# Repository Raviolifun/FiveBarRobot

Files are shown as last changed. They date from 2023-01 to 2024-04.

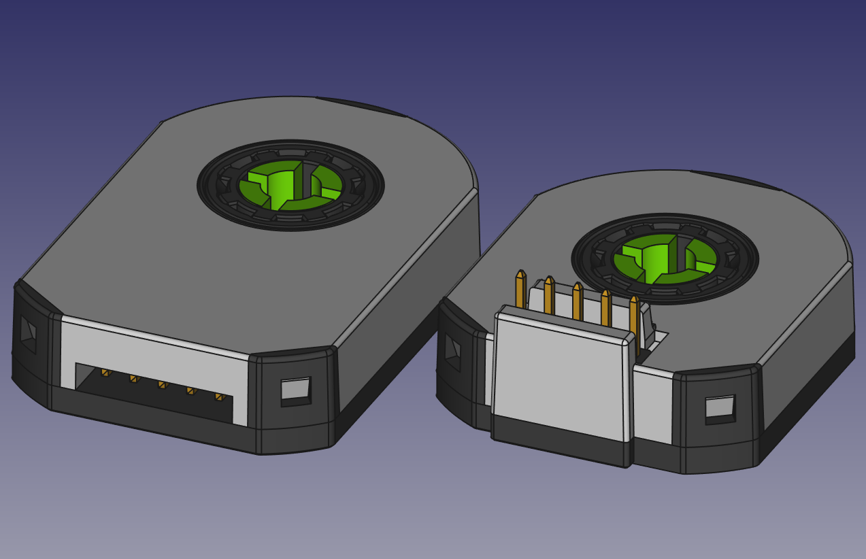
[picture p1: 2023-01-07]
CAD_Model/Motor/Electronics/cui-devices-atm102-atm103-encoders-1.snapshot.5/Encoders.png

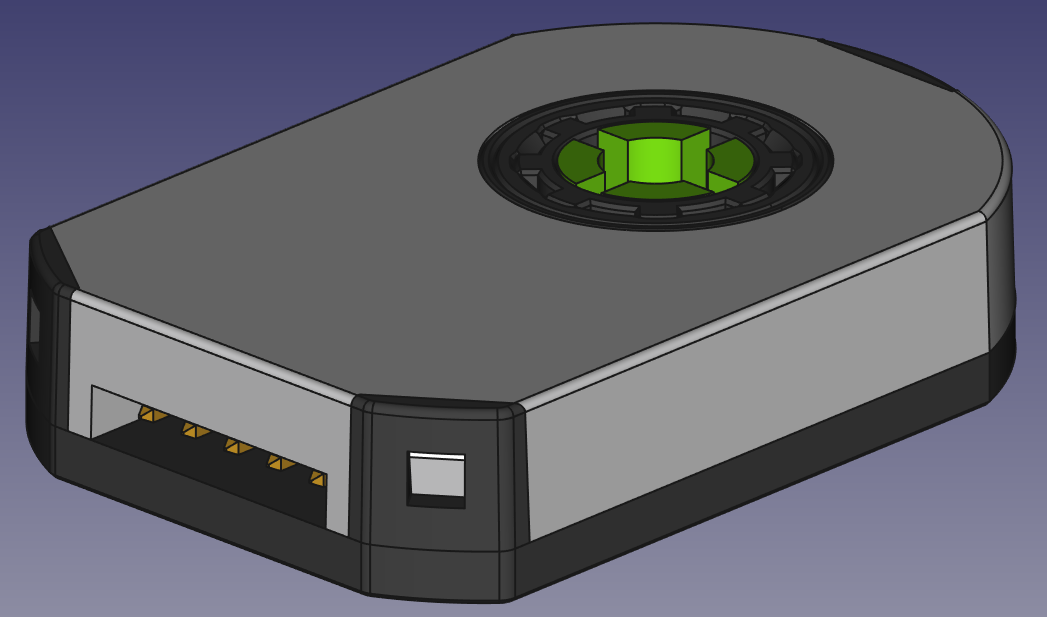
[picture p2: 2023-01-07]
CAD_Model/Motor/Electronics/cui-devices-atm102-atm103-encoders-1.snapshot.5/ATM102 Encoder.png

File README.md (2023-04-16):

Five Bar Robot
====================


Air Hockey Playing Robot
---------------------
Air hockey is used as a demonstration for the five bar robot's control.

Installation instructions
---------------------
Using this [guide](https://roboticsbackend.com/using-ros-on-raspberry-pi-best-practices/)
we downloaded Ubuntu Mate for the raspberry pi.
In tandem, we used this [guide](https://ubuntu-mate.org/raspberry-pi/install/)
to install the right version for our case (arm64 Jammy Jellyfish, 22.04.1 LTS.)
These instructions were not followed exactly, and we used a different flasher called balenaEtcher.

You will have to install a few python packages.

SAMPLE FOR WHAT THIS LOOKS LIKE IN THE README

Refer to the KivyMD page for installing the ui components https://github.com/kivymd/KivyMD
You will have to run these pip install commands for the app to work.
For all other installations, install based on the error messages on import.
```bash
pip install https://github.com/kivy/kivy/archive/master.zip
pip install https://github.com/kivymd/KivyMD/archive/master.zip
```

Hardware Requirements
---------------------
This project was built to run on Ubuntu Mate for the raspberry pi. However, many of the python files included in this
repository can run on Windows machines with no issues.

When first connecting to the ODrive, your computer may have difficultly communicating with the device.
This is often because your computer lacks the drivers required to communicate with the device.
These can be installed by using [Zadig](https://zadig.akeo.ie/), viewing all devices via the options menu, and then
installing "WinUSB" to the native interface for use with the odrivetool. Restart the computer if issues persist.
If none of these options work, refer to the [Odrive documentation](https://docs.odriverobotics.com/v/0.5.5/troubleshooting.html#troubleshooting) for trouble shooting.

The Story
---------------------

### The Inspiration
I enjoy doing fun projects, why else would you make something like this? Actually, it was a project I wanted to do for my
honor's thesis for a class I had been a TA for. I thought the rich dynamics and its design would allow for a really fun
project for the students to work on, so I decided to make it happen!

### What it does
A vision system located above the table tells the 5-bar where to position itself
with respect to the table. This is then fed through a coordinate transform before inverse kinematics are used to determine
possible joint angle that would satisfy the desired positions. At this point, a path is planned between
the current location and the desired location, at which point a following algorithm is used so the 5-bar can make its
way to the final position.

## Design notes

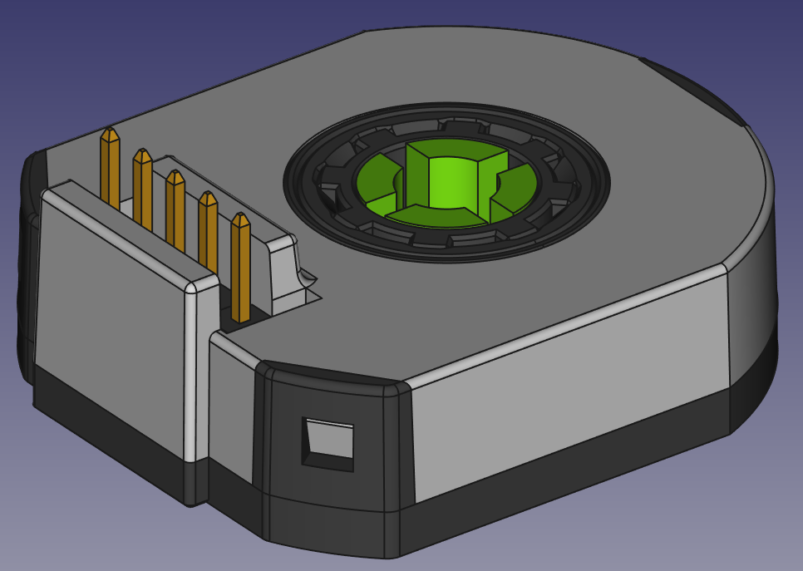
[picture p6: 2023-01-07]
CAD_Model/Motor/Electronics/cui-devices-atm102-atm103-encoders-1.snapshot.5/ATM103 Encoder.png

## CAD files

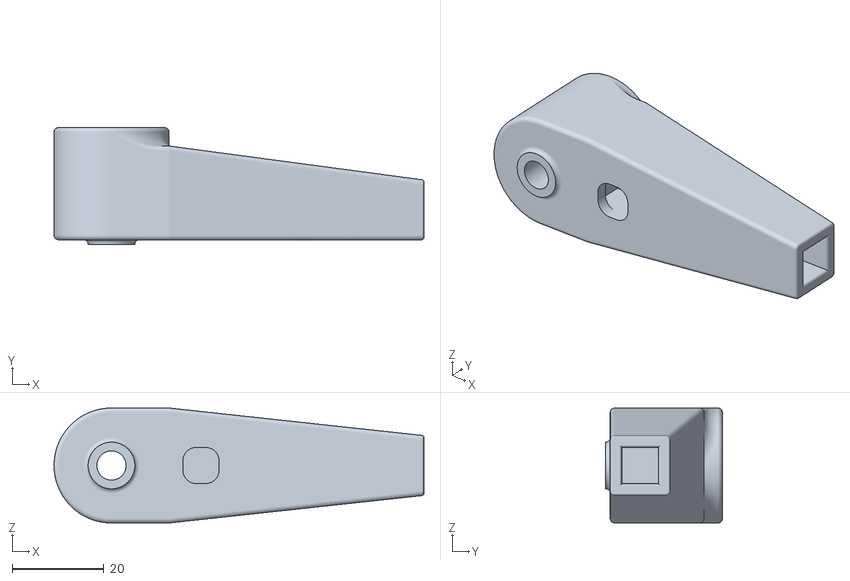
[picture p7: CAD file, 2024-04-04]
CAD_Model/Export3DPrinting/Save_LinkageMainV2.STL
80.4 x 25.4 x 25.0

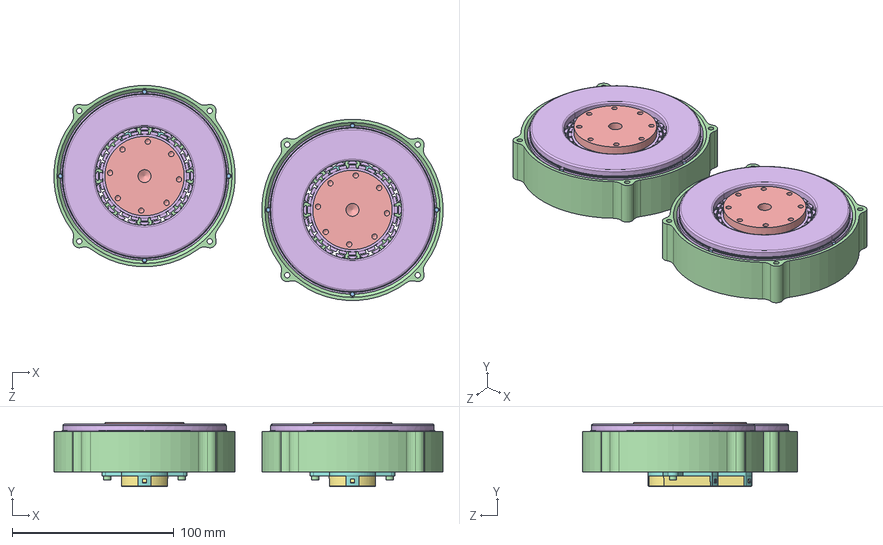
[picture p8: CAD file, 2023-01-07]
CAD_Model/Full_ASM.SLDASM
240.2 x 39.5 x 132.7 mm
0.500 ID x 0.875 OD x 0.281 WD (Radial Bearing) (217-3337) x 4
97633A200_External Retaining Ring x 2
97049A330_Undersized Dowel Pin x 8
91290A100_Black-Oxide Alloy Steel Socket Head Screw x 4
Body007^Array002_ATM102 Encoder(2)_ATM102 Encoder x 10
Body008^Array003_ATM102 Encoder(2)_ATM102 Encoder x 10
Body^ATM102 Encoder(2)_ATM102 Encoder x 2
Body001^ATM102 Encoder(2)_ATM102 Encoder x 2
Chamfer002^ATM102 Encoder(2)_ATM102 Encoder x 2
Chamfer004^ATM102 Encoder(2)_ATM102 Encoder x 2
Body006^ATM102 Encoder(2)_ATM102 Encoder x 2
Stator x 2
Rotor x 2
RI100-210120 x 2

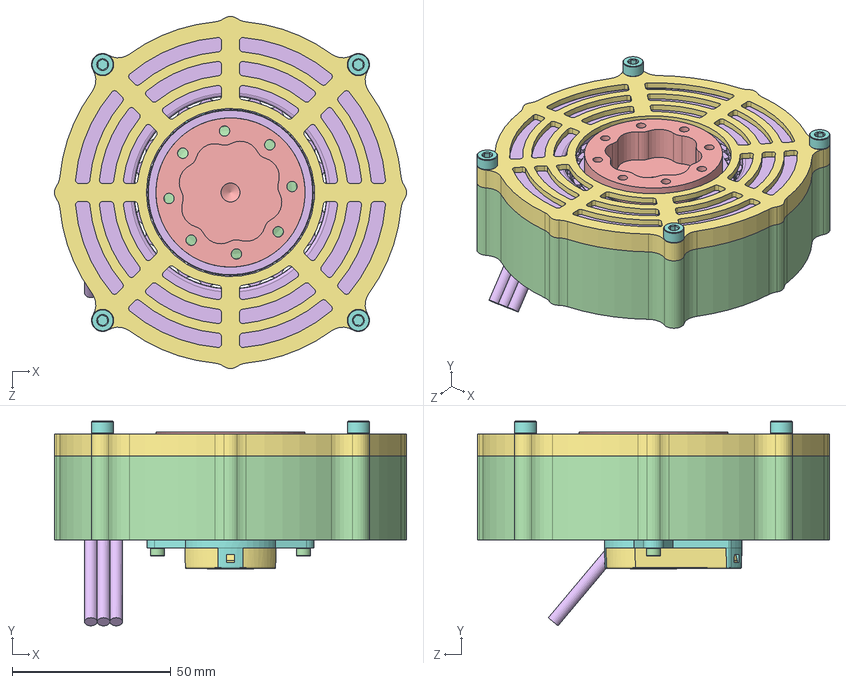
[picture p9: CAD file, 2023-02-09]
CAD_Model/Motor/MainMotorASM.SLDASM
110.9 x 64.5 x 110.9 mm
60355K45_Ball Bearing x 2
97633A170_External Retaining Ring
97049A330_Undersized Dowel Pin x 4
91290A100_Black-Oxide Alloy Steel Socket Head Screw x 2
Body007^Array002_ATM102 Encoder(2)_ATM102 Encoder x 5
Body008^Array003_ATM102 Encoder(2)_ATM102 Encoder x 5
Body^ATM102 Encoder(2)_ATM102 Encoder
Body001^ATM102 Encoder(2)_ATM102 Encoder
Chamfer002^ATM102 Encoder(2)_ATM102 Encoder
Chamfer004^ATM102 Encoder(2)_ATM102 Encoder
Body006^ATM102 Encoder(2)_ATM102 Encoder
Stator
Rotor
RI100-210120
Part2^MainMotorASM
91290A144_Alloy Steel Socket Head Screw x 4

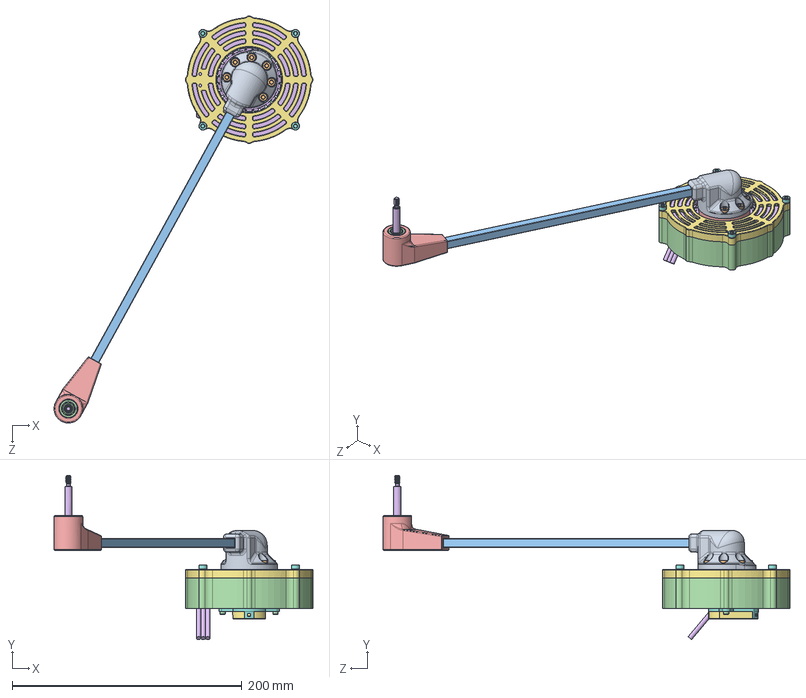
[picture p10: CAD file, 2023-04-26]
CAD_Model/Linkage/Linkage_ASM.SLDASM
225.2 x 142.9 x 354.1 mm
60355K45_Ball Bearing x 2
97633A170_External Retaining Ring
97049A330_Undersized Dowel Pin x 4
91290A100_Black-Oxide Alloy Steel Socket Head Screw x 2
Body007^Array002_ATM102 Encoder(2)_ATM102 Encoder x 5
Body008^Array003_ATM102 Encoder(2)_ATM102 Encoder x 5
Body^ATM102 Encoder(2)_ATM102 Encoder
Body001^ATM102 Encoder(2)_ATM102 Encoder
Chamfer002^ATM102 Encoder(2)_ATM102 Encoder
Chamfer004^ATM102 Encoder(2)_ATM102 Encoder
Body006^ATM102 Encoder(2)_ATM102 Encoder
Stator
Rotor
RI100-210120
Part2^MainMotorASM
91290A144_Alloy Steel Socket Head Screw x 4
Shoulder Mount
91290A140_Alloy Steel Socket Head Screw x 6
Shoulder Arm
6455K8_Plastic Ball Bearing x 2
Elbow1V2
93897A322_Nylon Shoulder Screws

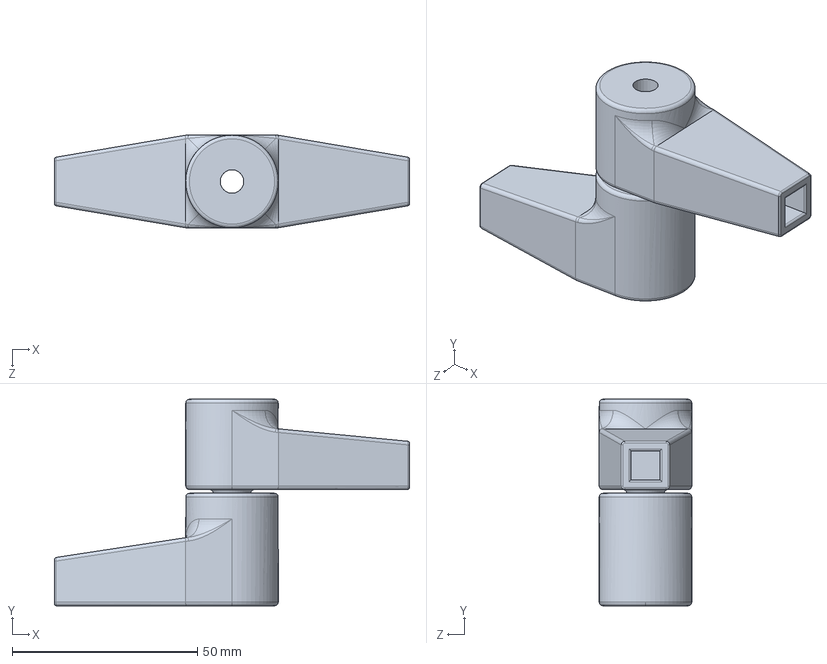
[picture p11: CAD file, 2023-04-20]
CAD_Model/Linkage/LinkageMainV2.SLDPRT
95.9 x 55.8 x 25.0 mm

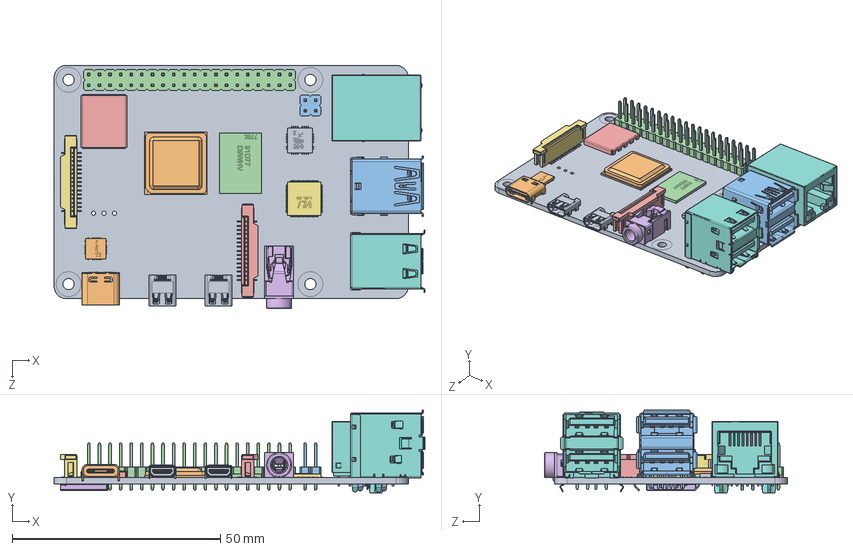
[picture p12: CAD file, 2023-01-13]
CAD_Model/Electronics/raspberry-pi-4-model-b-1.snapshot.3/Raspberry Pi 4 Model B.SLDASM
89.0 x 19.9 x 58.4 mm
PCB, RPi4ModelB
Broadcom BCM2711B0 CPU, RPi4ModelB
2.54 mm DUPONT MALE PIN HEADER, POE, 2X2, RPi4ModelB
2.54 mm DUPONT MALE PIN HEADER, IO, 2X20, RPi4ModelB
Camera Connector, RPi4ModelB
Microphone Plug, RPi4ModelB
Display Connector, RPi4ModelB
Gigabit Ethernet Port, RPi4ModelB
Female Micro HDMI Connector, RPi4ModelB x 2
Female USB Type C Connector, RPi4ModelB
2X USB3.0 PORTS, RPi4ModelB
91D77 D9WHV 778K, 4 GB LPDDR4 SDRAM, RPi4ModelB
Cypress CYW43455 Wireless Module Cover, RPi4ModelB
SD Card Slot, RPi4ModelB
VIA VL805 PCIe USB 3.0 controller, RPi4ModelB
2X USB2.0 PORTS, RPi4ModelB
Broadcom BCM54213PE Gigabit Ethernet Transceiver, RPi4ModelB
MxL7704 Universal PMIC, RPi4ModelB

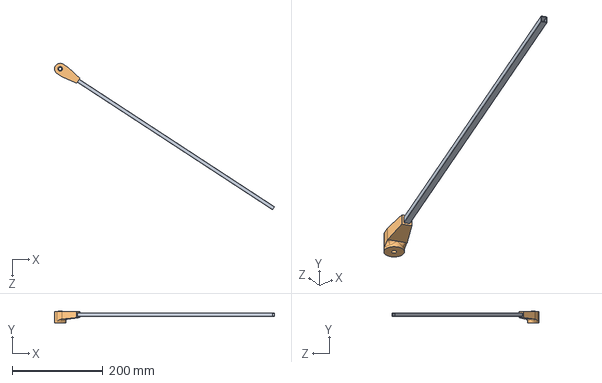
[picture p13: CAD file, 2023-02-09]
CAD_Model/Linkage/Forarm_ASM.SLDASM
485.6 x 25.4 x 323.5 mm
Forearm
Elbow2V2

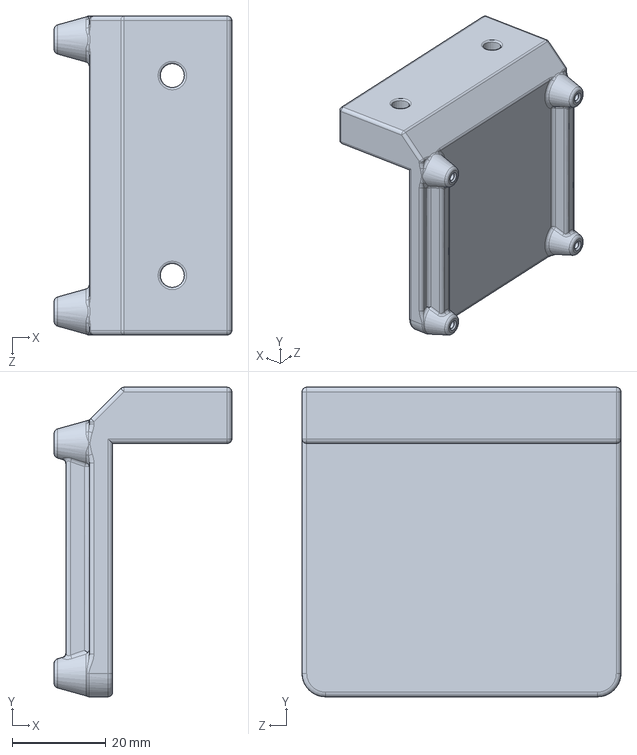
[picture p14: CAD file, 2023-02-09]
CAD_Model/AirTable/Raspi Controller Mount.SLDPRT
37.9 x 66.0 x 68.0 mm

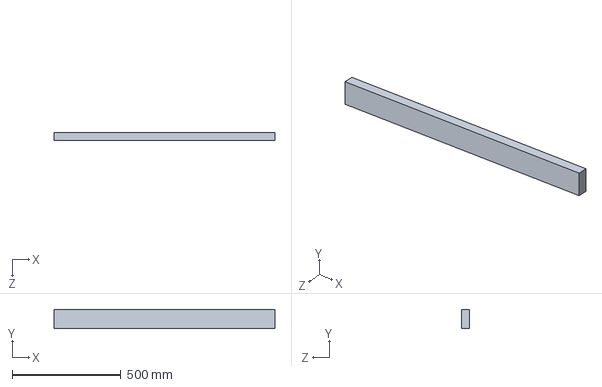
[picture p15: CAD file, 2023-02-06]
CAD_Model/AirTable/SubParts/BottomSupport3.SLDPRT
1016.0 x 88.9 x 38.1 mm

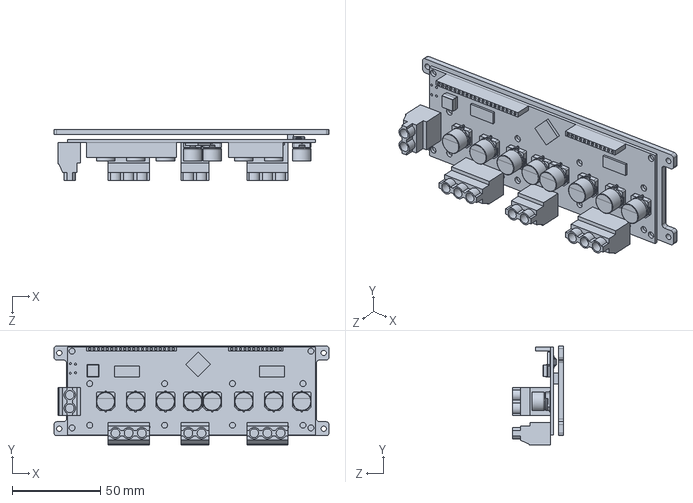
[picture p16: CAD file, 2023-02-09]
CAD_Model/Electronics/motor-driver-odrive-v3-6-1.snapshot.2/motor driver ODRIVE V3.6.SLDPRT
156.0 x 56.1 x 29.1 mm

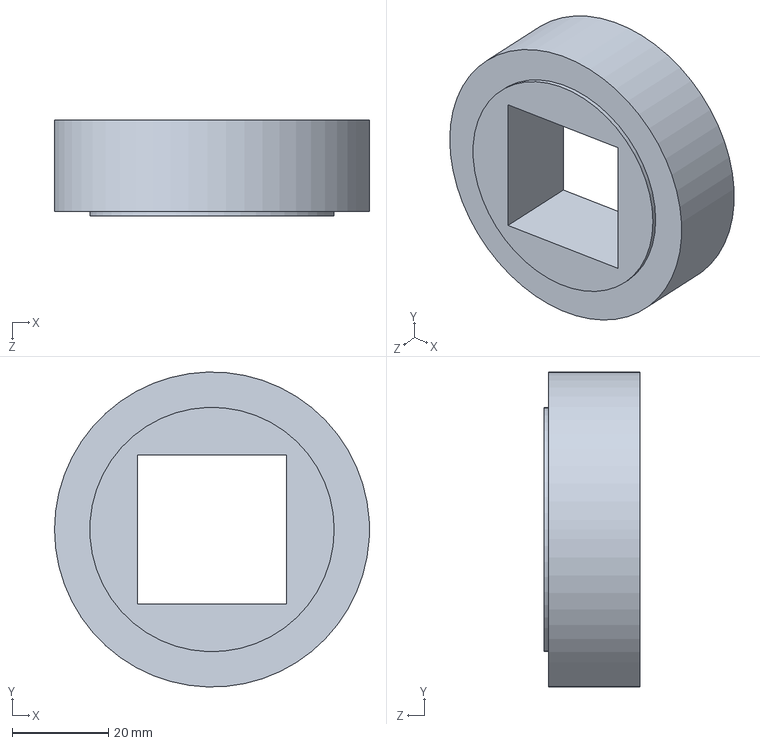
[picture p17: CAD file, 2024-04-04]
CAD_Model/Electronics/NeopixelRinglightMount.SLDPRT
65.5 x 65.5 x 20.0 mm

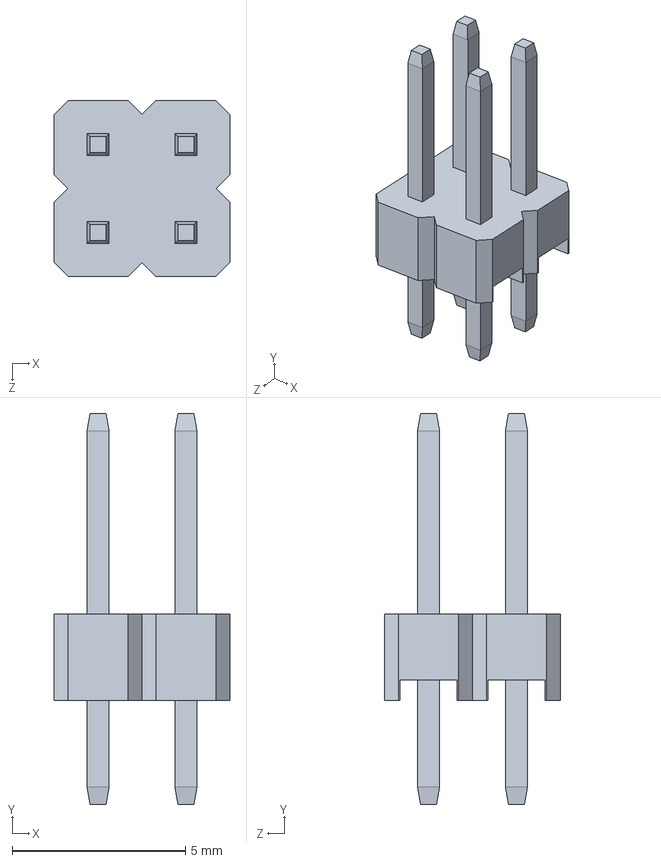
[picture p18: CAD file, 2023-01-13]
CAD_Model/Electronics/raspberry-pi-4-model-b-1.snapshot.3/2.54 mm DUPONT MALE PIN HEADER, POE, 2X2, RPi4ModelB.SLDPRT
5.08 x 11.3 x 5.08 mm

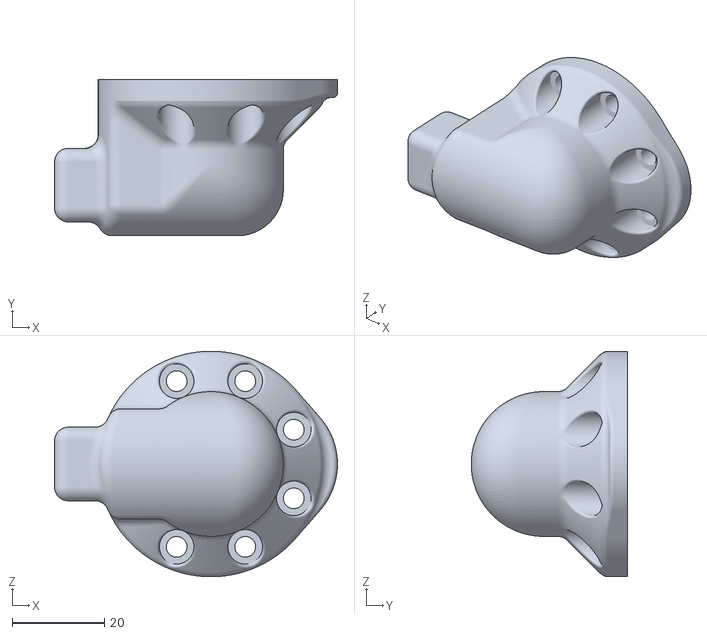
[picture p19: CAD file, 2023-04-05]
CAD_Model/Export3DPrinting/ToPrint/Robot_ShoulderMount.STL
61.5 x 34.0 x 49.0

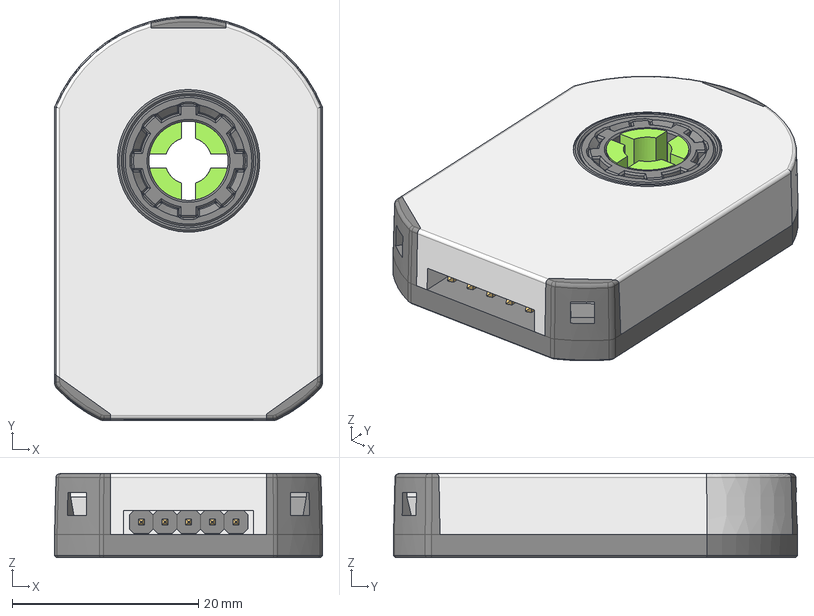
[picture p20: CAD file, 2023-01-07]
CAD_Model/Motor/Electronics/cui-devices-atm102-atm103-encoders-1.snapshot.5/ATM102 Encoder.step
28.8 x 43.4 x 9.03 mm

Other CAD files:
CAD_Model/Linkage/Save_LinkageMainV2.SLDPRT
CAD_Model/Motor/Electronics/cui-devices-atm102-atm103-encoders-1.snapshot.5/FreeCAD Files/Encoders.FCStd
CAD_Model/Motor/StatorRotor/RI100-210120.stp
CAD_Model/TestSystem/TestSystem_1.STL
CAD_Model/AirTable/Air Table.SLDPRT
CAD_Model/AirTable/Air TableTOP.SLDDRW
CAD_Model/AirTable/Ducts.STEP
CAD_Model/AirTable/Edge_Guard.SLDPRT
CAD_Model/AirTable/Electronics Mount.SLDPRT
CAD_Model/AirTable/Motor Controller Mount.SLDPRT
CAD_Model/AirTable/MotorMount.SLDPRT
CAD_Model/AirTable/Mounting for Motors.SLDPRT
CAD_Model/AirTable/Puck.3mf
CAD_Model/AirTable/Puck.SLDPRT
CAD_Model/AirTable/Puck.STL
CAD_Model/AirTable/SubParts/BottomSupport.SLDDRW
CAD_Model/AirTable/SubParts/BottomSupport.SLDPRT
CAD_Model/AirTable/SubParts/BottomSupport2.SLDPRT
CAD_Model/AirTable/SubParts/BottomSupport4.SLDPRT
CAD_Model/AirTable/SubParts/Corner Locator1.SLDPRT
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

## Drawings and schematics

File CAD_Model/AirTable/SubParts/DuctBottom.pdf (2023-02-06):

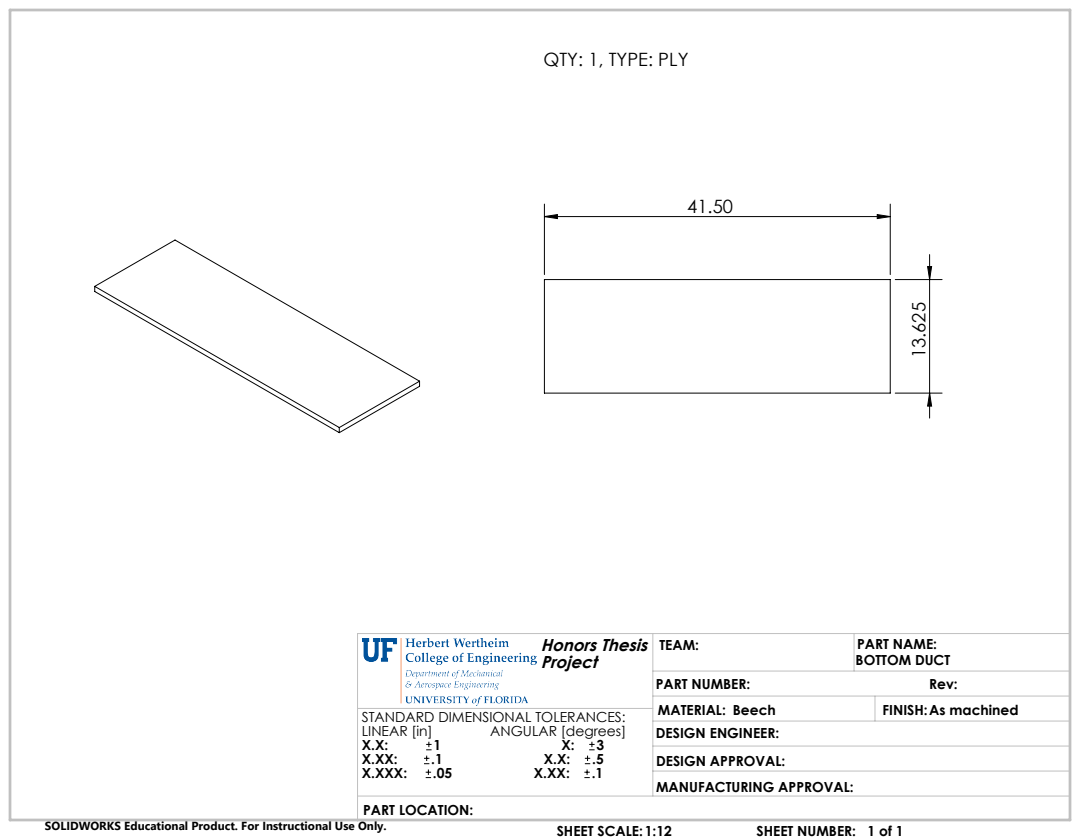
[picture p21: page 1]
Honors Thesis; DESIGN ENGINEER: DESIGN APPROVAL:; PART NUMBER:; SHEET SCALE:; SHEET NUMBER:; Beech; As machined; PART NAME: BOTTOM DUCT; LINEAR [in]; ANGULAR [degrees]; X.XXX:; MANUFACTURING APPROVAL:

QTY: 1, TYPE: PLY

STANDARD DIMENSIONAL TOLERANCES:
PART LOCATION:

SOLIDWORKS Educational Product. For Instructional Use Only.

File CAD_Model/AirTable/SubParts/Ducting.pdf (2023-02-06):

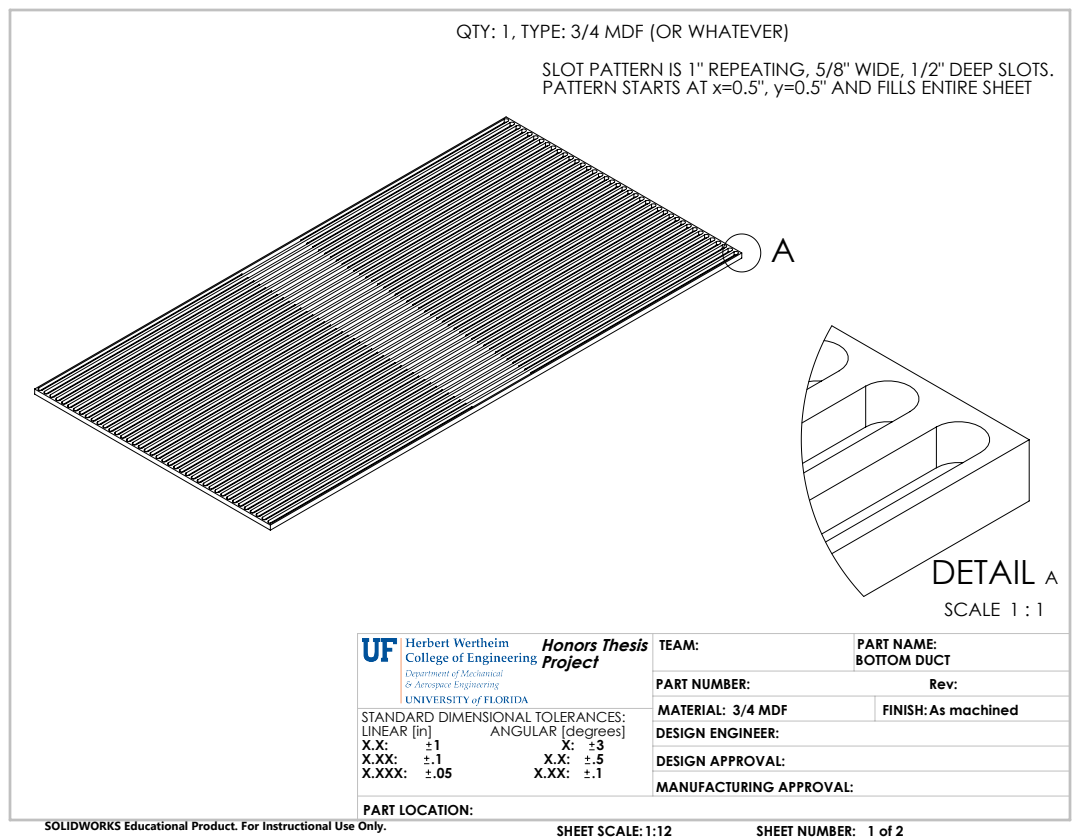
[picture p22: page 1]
DETAIL A; SCALE 1 : 1; Honors Thesis; DESIGN ENGINEER: DESIGN APPROVAL:; PART NUMBER:; SHEET SCALE:; SHEET NUMBER:; 3/4 MDF; As machined; PART NAME: BOTTOM DUCT; LINEAR [in]; ANGULAR [degrees]; X.XXX:; MANUFACTURING APPROVAL:

QTY: 1, TYPE: 3/4 MDF (OR WHATEVER)

SLOT PATTERN IS 1" REPEATING, 5/8" WIDE, 1/2" DEEP SLOTS.
PATTERN STARTS AT x=0.5", y=0.5" AND FILLS ENTIRE SHEET

STANDARD DIMENSIONAL TOLERANCES:
PART LOCATION:

SOLIDWORKS Educational Product. For Instructional Use Only.

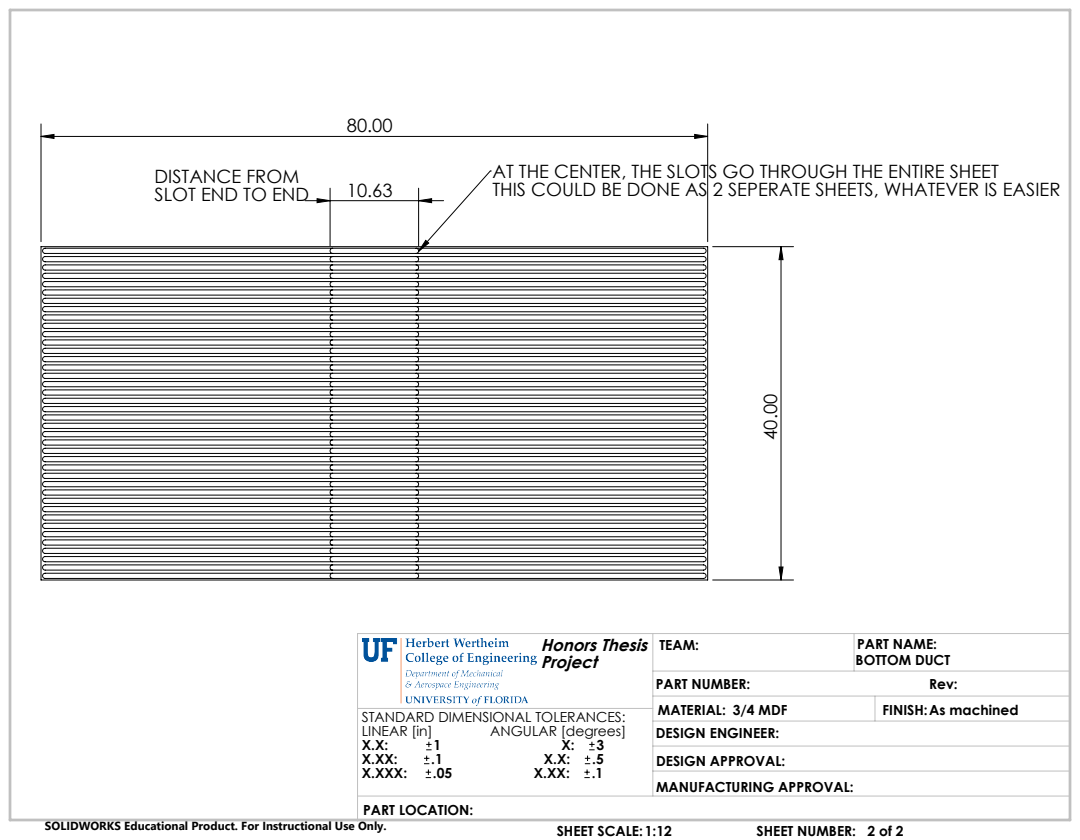
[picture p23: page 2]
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

AT THE CENTER, THE SLOTS GO THROUGH THE ENTIRE SHEET

THIS COULD BE DONE AS 2 SEPERATE SHEETS, WHATEVER IS EASIER DISTANCE FROM
SLOT END TO END

STANDARD DIMENSIONAL TOLERANCES:
PART LOCATION:

SOLIDWORKS Educational Product. For Instructional Use Only.

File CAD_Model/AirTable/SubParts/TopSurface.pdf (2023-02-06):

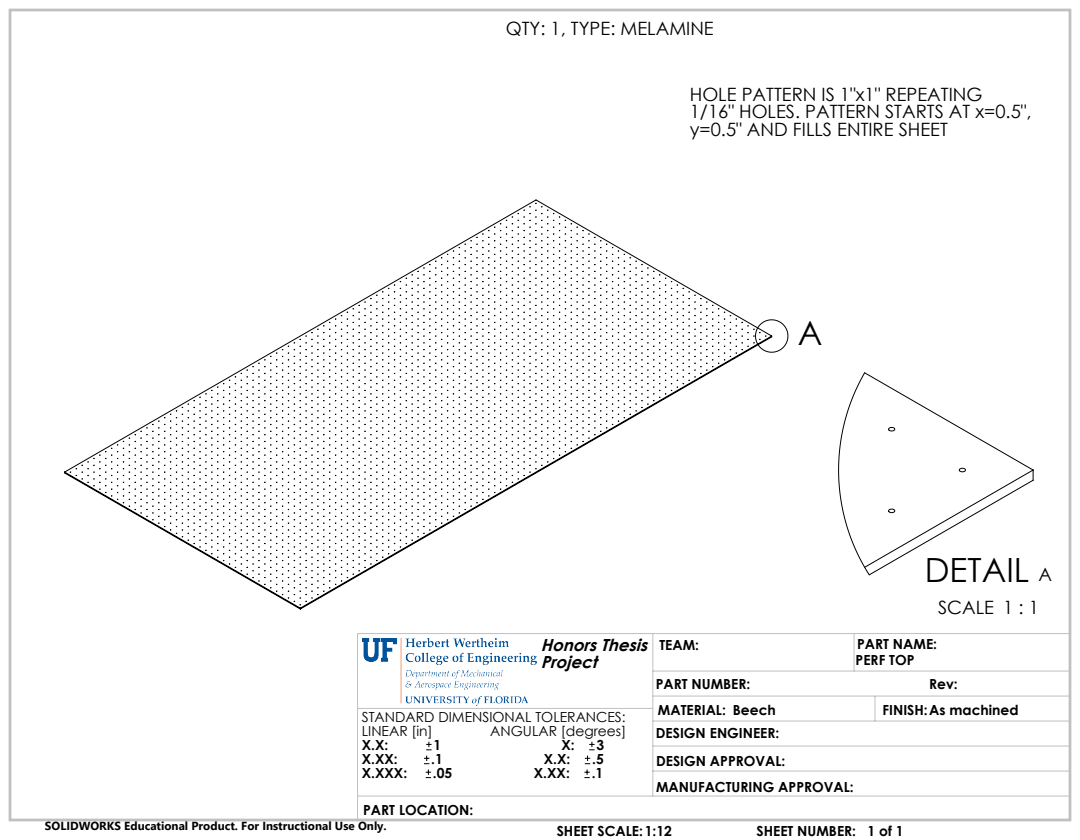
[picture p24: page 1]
DETAIL A; SCALE 1 : 1; Honors Thesis; DESIGN ENGINEER: DESIGN APPROVAL:; PART NUMBER:; SHEET SCALE:; SHEET NUMBER:; Beech; As machined; PART NAME: PERF TOP; LINEAR [in]; ANGULAR [degrees]; X.XXX:; MANUFACTURING APPROVAL:

QTY: 1, TYPE: MELAMINE

HOLE PATTERN IS 1"x1" REPEATING
1/16" HOLES. PATTERN STARTS AT x=0.5",
y=0.5" AND FILLS ENTIRE SHEET

STANDARD DIMENSIONAL TOLERANCES:
PART LOCATION:

SOLIDWORKS Educational Product. For Instructional Use Only.

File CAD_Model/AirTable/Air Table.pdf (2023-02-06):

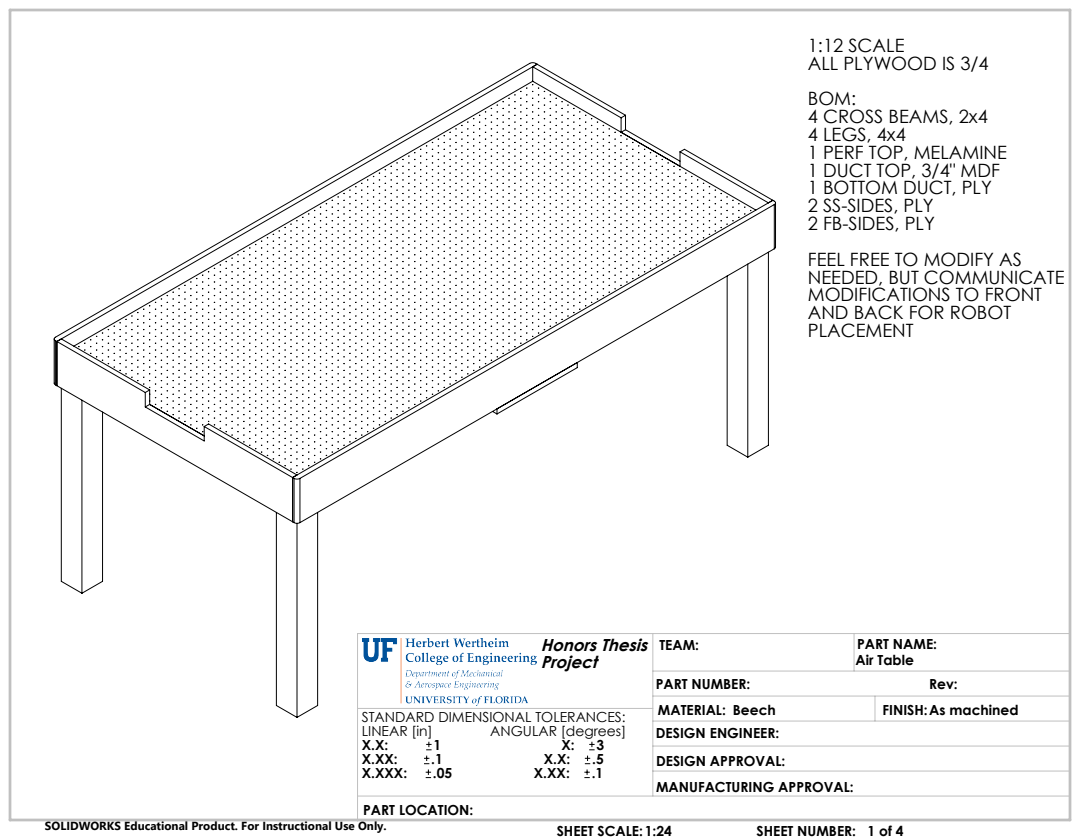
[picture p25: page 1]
Honors Thesis; DESIGN ENGINEER: DESIGN APPROVAL:; PART NUMBER:; SHEET SCALE:; SHEET NUMBER:; Beech; As machined; PART NAME: Air Table; LINEAR [in]; ANGULAR [degrees]; X.XXX:; MANUFACTURING APPROVAL:

1:12 SCALE
ALL PLYWOOD IS 3/4
BOM:
4 CROSS BEAMS, 2x4
4 LEGS, 4x4
1 PERF TOP, MELAMINE
1 DUCT TOP, 3/4" MDF
1 BOTTOM DUCT, PLY
2 SS-SIDES, PLY
2 FB-SIDES, PLY
FEEL FREE TO MODIFY AS
NEEDED, BUT COMMUNICATE
MODIFICATIONS TO FRONT
AND BACK FOR ROBOT
PLACEMENT

STANDARD DIMENSIONAL TOLERANCES:
PART LOCATION:

SOLIDWORKS Educational Product. For Instructional Use Only.

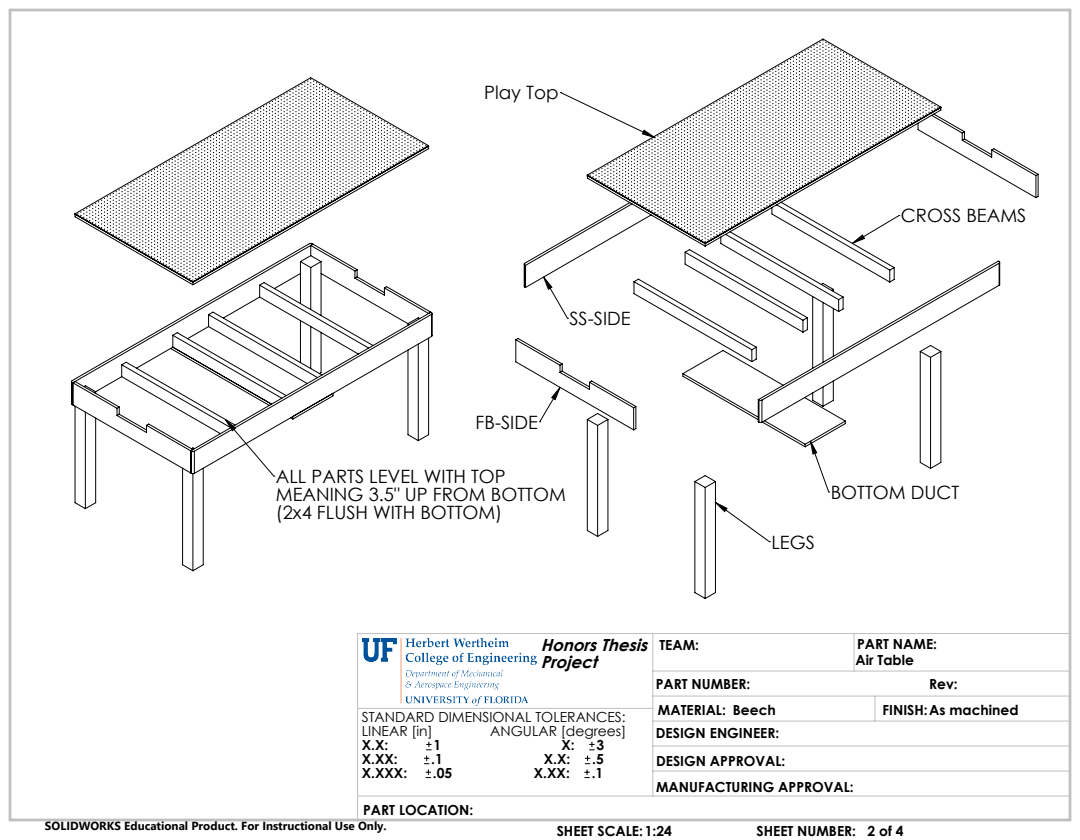
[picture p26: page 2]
CROSS BEAMS; BOTTOM DUCT; Play Top; Honors Thesis; DESIGN ENGINEER: DESIGN APPROVAL:; PART NUMBER:; Beech; As machined; PART NAME: Air Table; LINEAR [in]; ANGULAR [degrees]; X.XXX:

ALL PARTS LEVEL WITH TOP
MEANING 3.5" UP FROM BOTTOM
(2x4 FLUSH WITH BOTTOM)

STANDARD DIMENSIONAL TOLERANCES:

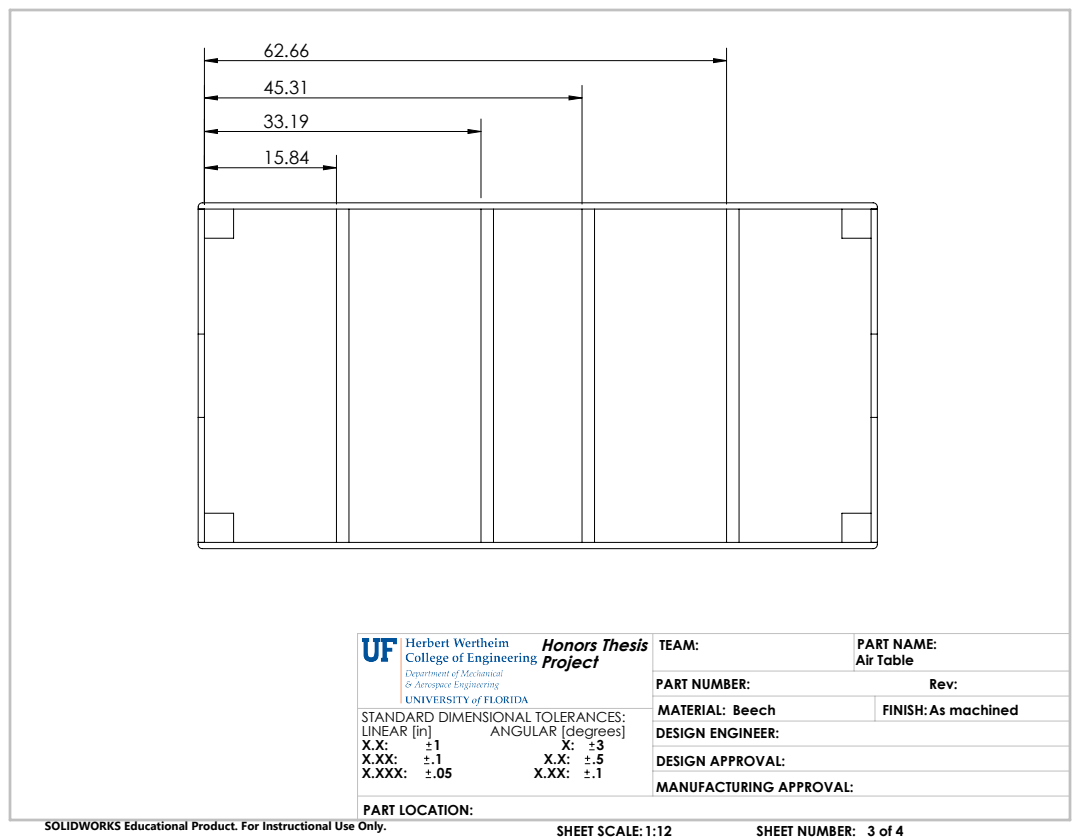
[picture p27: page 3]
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

STANDARD DIMENSIONAL TOLERANCES:

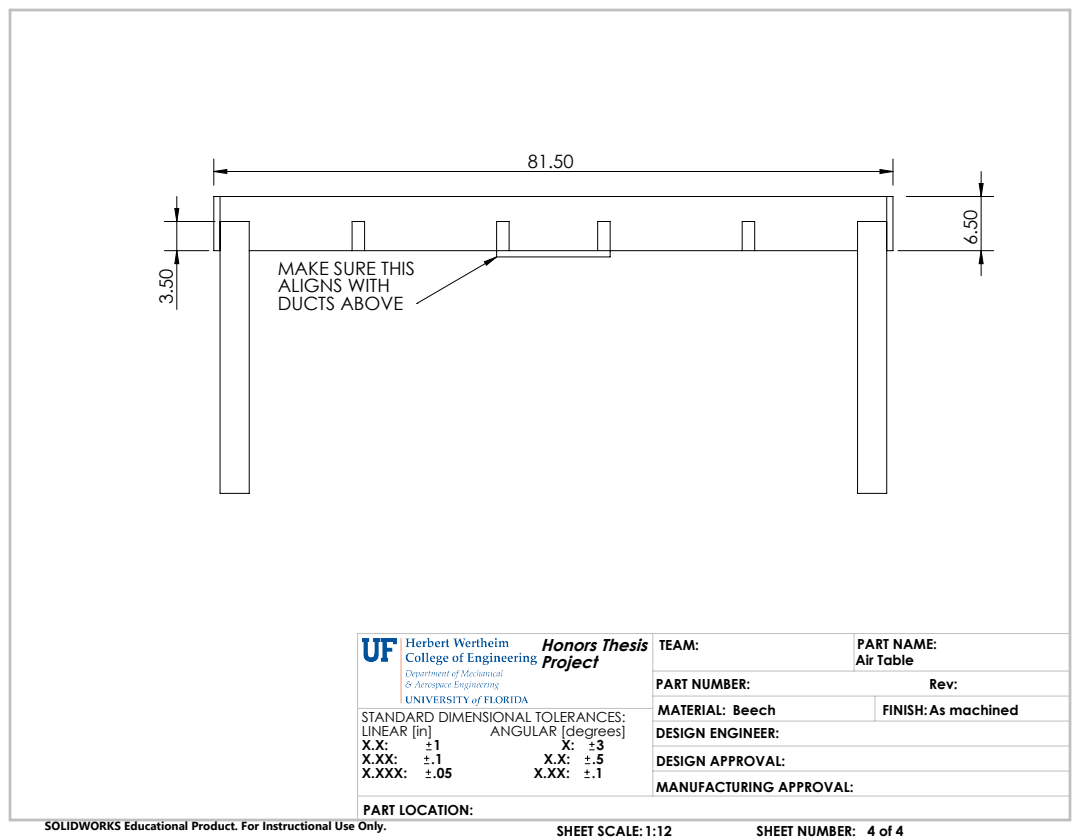
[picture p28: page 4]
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

MAKE SURE THIS
ALIGNS WITH
DUCTS ABOVE

STANDARD DIMENSIONAL TOLERANCES:

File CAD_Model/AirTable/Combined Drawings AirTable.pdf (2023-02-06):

Honors Thesis Project; DESIGN ENGINEER: DESIGN APPROVAL:; PART NUMBER:; MATERIAL:; FINISH:; SHEET SCALE:; SHEET NUMBER:; Beech; As machined; PART NAME: Air Table; Rev:; LINEAR [in]; ANGULAR [degrees]; X.XXX:; MANUFACTURING APPROVAL:; TEAM:

1:12 SCALE
ALL PLYWOOD IS 3/4
BOM:
4 CROSS BEAMS, 2x4
4 LEGS, 4x4
1 PERF TOP, MELAMINE
1 DUCT TOP, 3/4" MDF
1 BOTTOM DUCT, PLY
2 SS-SIDES, PLY
2 FB-SIDES, PLY
FEEL FREE TO MODIFY AS
NEEDED, BUT COMMUNICATE
MODIFICATIONS TO FRONT
AND BACK FOR ROBOT
PLACEMENT

STANDARD DIMENSIONAL TOLERANCES:
PART LOCATION:

SOLIDWORKS Educational Product. For Instructional Use Only.

LEGS; FB-SIDE; SS-SIDE; CROSS BEAMS; BOTTOM DUCT; Play Top; Honors Thesis Project; DESIGN ENGINEER: DESIGN APPROVAL:; PART NUMBER:; MATERIAL:; FINISH:; Beech; As machined; PART NAME: Air Table; Rev:; LINEAR [in]; ANGULAR [degrees]; X.XXX:; TEAM:

ALL PARTS LEVEL WITH TOP
MEANING 3.5" UP FROM BOTTOM
(2x4 FLUSH WITH BOTTOM)

STANDARD DIMENSIONAL TOLERANCES:

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

STANDARD DIMENSIONAL TOLERANCES:

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

MAKE SURE THIS
ALIGNS WITH
DUCTS ABOVE

STANDARD DIMENSIONAL TOLERANCES:

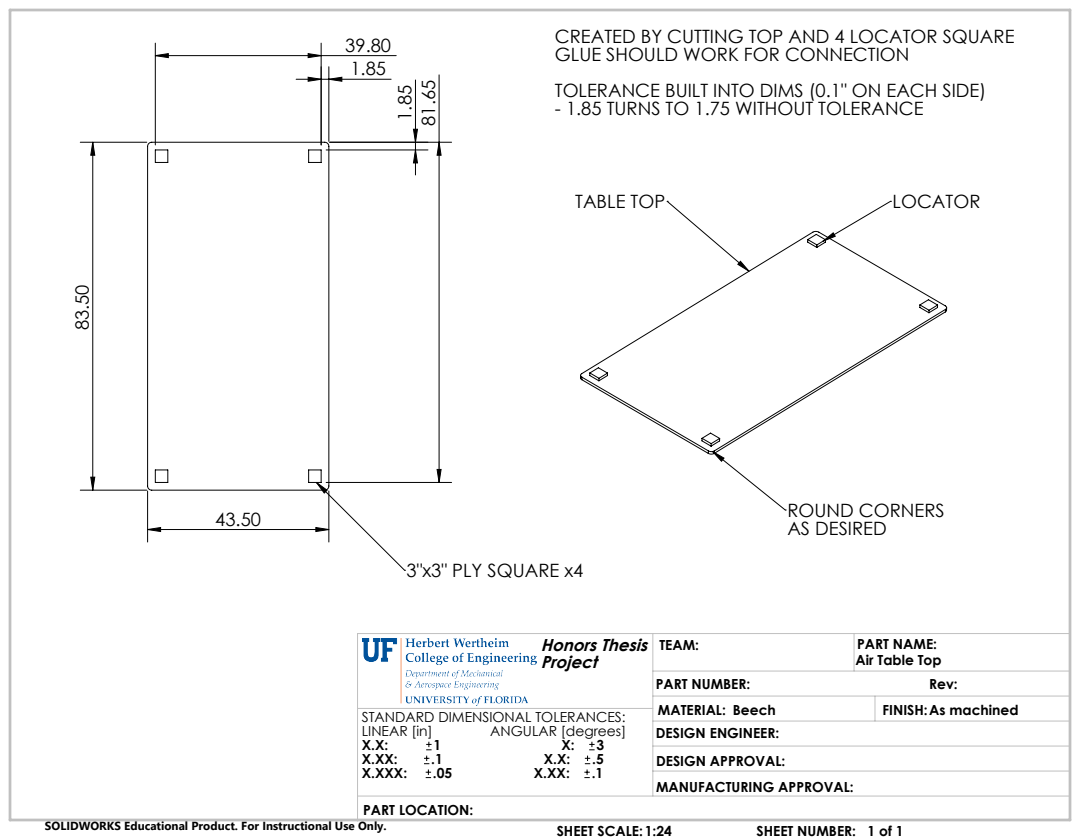
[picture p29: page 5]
TABLE TOP; LOCATOR; ROUND CORNERS AS DESIRED; 3"x3" PLY SQUARE x4; Honors Thesis Project; DESIGN ENGINEER: DESIGN APPROVAL:; PART NUMBER:; MATERIAL:; FINISH:; Beech; As machined; Rev:; LINEAR [in]; ANGULAR [degrees]; X.XXX:; TEAM:

CREATED BY CUTTING TOP AND 4 LOCATOR SQUARE
GLUE SHOULD WORK FOR CONNECTION
TOLERANCE BUILT INTO DIMS (0.1" ON EACH SIDE)
- 1.85 TURNS TO 1.75 WITHOUT TOLERANCE

PART NAME:
Air Table Top

STANDARD DIMENSIONAL TOLERANCES:

DETAIL A; SCALE 1 : 1; Honors Thesis Project; DESIGN ENGINEER: DESIGN APPROVAL:; PART NUMBER:; MATERIAL:; FINISH:; 3/4 MDF; As machined; PART NAME: BOTTOM DUCT; Rev:; LINEAR [in]; ANGULAR [degrees]; X.XXX:; TEAM:

QTY: 1, TYPE: 3/4 MDF (OR WHATEVER)

SLOT PATTERN IS 1" REPEATING, 5/8" WIDE, 1/2" DEEP SLOTS.
PATTERN STARTS AT x=0.5", y=0.5" AND FILLS ENTIRE SHEET

STANDARD DIMENSIONAL TOLERANCES:

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

AT THE CENTER, THE SLOTS GO THROUGH THE ENTIRE SHEET

THIS COULD BE DONE AS 2 SEPERATE SHEETS, WHATEVER IS EASIER DISTANCE FROM
SLOT END TO END

STANDARD DIMENSIONAL TOLERANCES:

DETAIL A; SCALE 1 : 1; Honors Thesis Project; DESIGN ENGINEER: DESIGN APPROVAL:; PART NUMBER:; MATERIAL:; FINISH:; Beech; As machined; PART NAME: PERF TOP; Rev:; LINEAR [in]; ANGULAR [degrees]; X.XXX:; TEAM:

QTY: 1, TYPE: MELAMINE

HOLE PATTERN IS 1"x1" REPEATING
1/16" HOLES. PATTERN STARTS AT x=0.5",
y=0.5" AND FILLS ENTIRE SHEET

STANDARD DIMENSIONAL TOLERANCES:

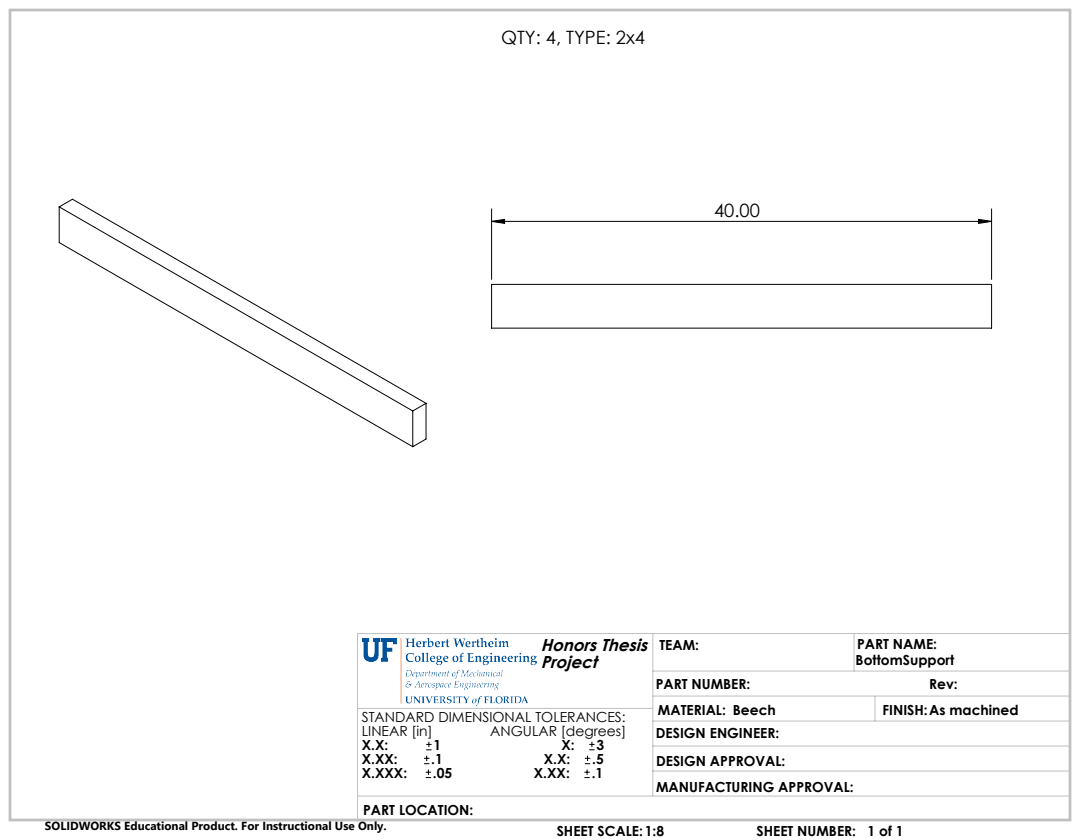
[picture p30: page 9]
QTY: 4, TYPE: 2x4; Honors Thesis Project; DESIGN ENGINEER: DESIGN APPROVAL:; PART NUMBER:; MATERIAL:; FINISH:; Beech; As machined; PART NAME: BottomSupport; Rev:; LINEAR [in]; ANGULAR [degrees]; X.XXX:; TEAM:

STANDARD DIMENSIONAL TOLERANCES:

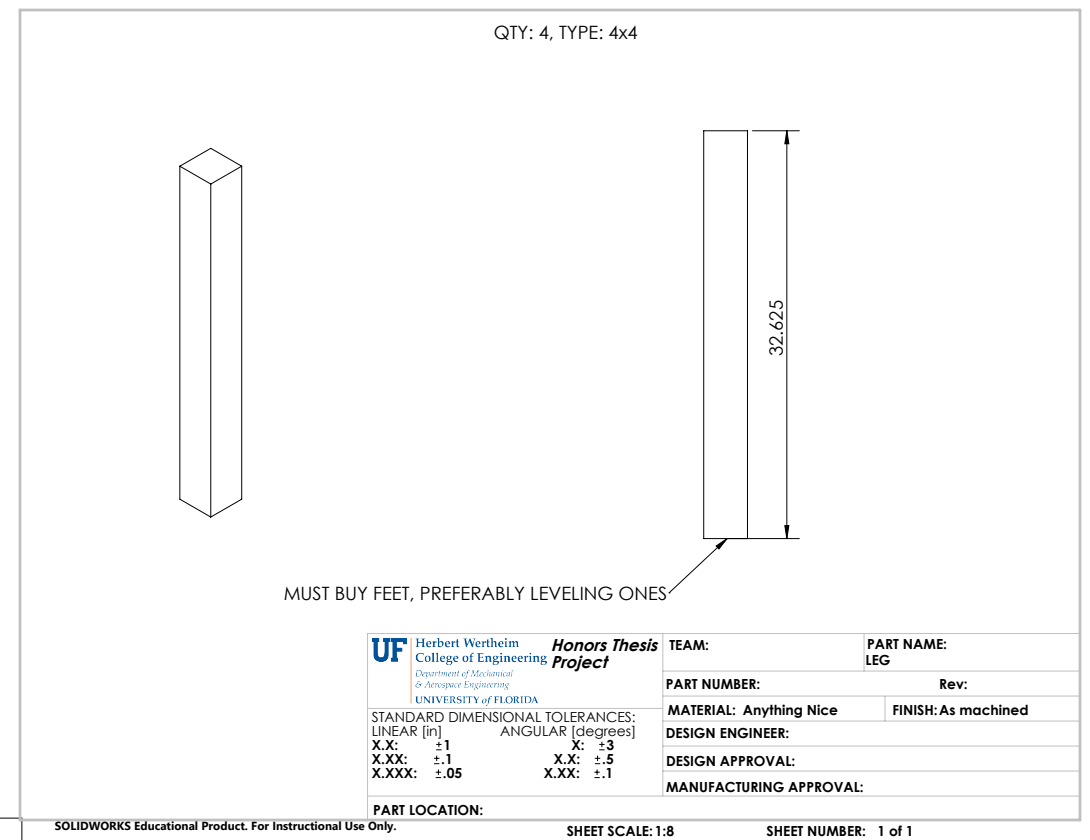
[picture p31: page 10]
QTY: 4, TYPE: 4x4; Honors Thesis Project; DESIGN ENGINEER: DESIGN APPROVAL:; PART NUMBER:; MATERIAL:; FINISH:; Anything Nice; As machined; PART NAME: LEG; Rev:; LINEAR [in]; ANGULAR [degrees]; X.XXX:; TEAM:

MUST BUY FEET, PREFERABLY LEVELING ONES

STANDARD DIMENSIONAL TOLERANCES:

Honors Thesis Project; DESIGN ENGINEER: DESIGN APPROVAL:; PART NUMBER:; MATERIAL:; FINISH:; Beech; As machined; PART NAME: BOTTOM DUCT; Rev:; LINEAR [in]; ANGULAR [degrees]; X.XXX:; TEAM:

QTY: 1, TYPE: PLY

STANDARD DIMENSIONAL TOLERANCES:

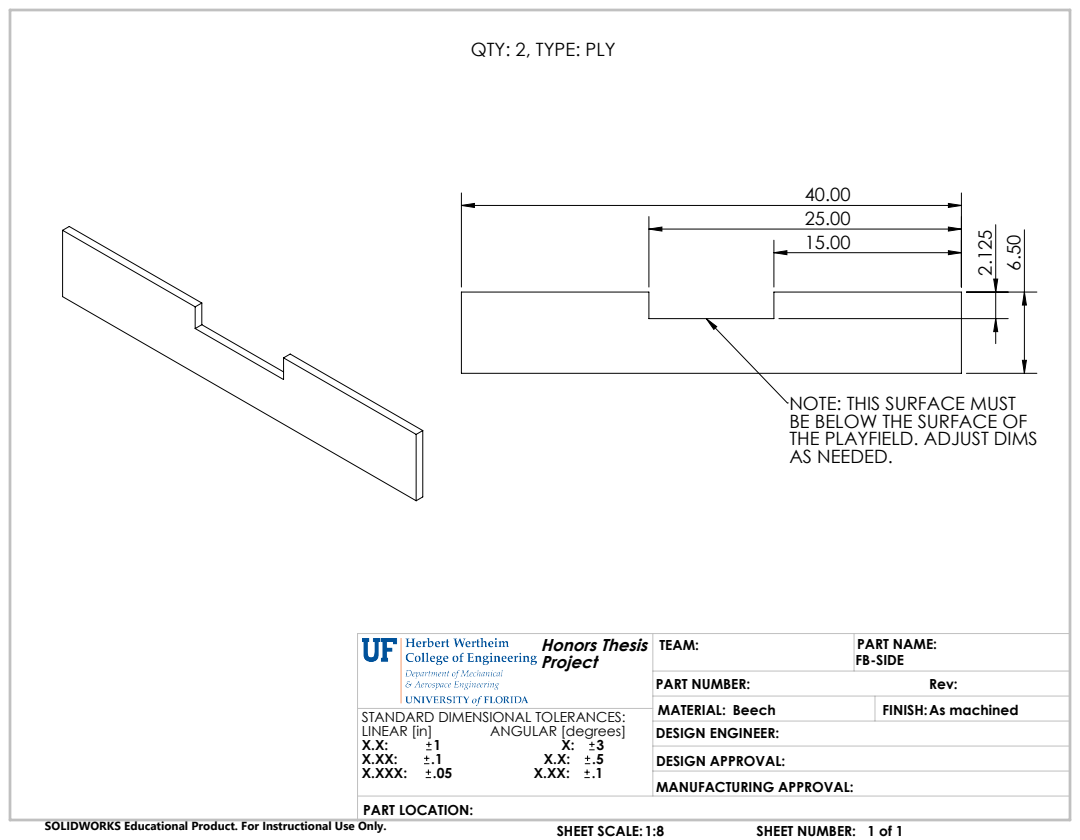
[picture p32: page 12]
Honors Thesis Project; DESIGN ENGINEER: DESIGN APPROVAL:; PART NUMBER:; MATERIAL:; FINISH:; Beech; As machined; PART NAME: FB-SIDE; Rev:; LINEAR [in]; ANGULAR [degrees]; X.XXX:; TEAM:

QTY: 2, TYPE: PLY

NOTE: THIS SURFACE MUST
BE BELOW THE SURFACE OF
THE PLAYFIELD. ADJUST DIMS
AS NEEDED.

STANDARD DIMENSIONAL TOLERANCES:
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

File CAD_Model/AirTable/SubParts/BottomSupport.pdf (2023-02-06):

QTY: 4, TYPE: 2x4; Honors Thesis; DESIGN ENGINEER: DESIGN APPROVAL:; PART NUMBER:; SHEET SCALE:; SHEET NUMBER:; Beech; As machined; PART NAME:; LINEAR [in]; ANGULAR [degrees]; X.XXX:; MANUFACTURING APPROVAL:

STANDARD DIMENSIONAL TOLERANCES:
PART LOCATION:

SOLIDWORKS Educational Product. For Instructional Use Only.

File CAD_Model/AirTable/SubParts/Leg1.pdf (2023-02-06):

QTY: 4, TYPE: 4x4; Honors Thesis; DESIGN ENGINEER: DESIGN APPROVAL:; PART NUMBER:; SHEET SCALE:; SHEET NUMBER:; Anything Nice; As machined; PART NAME:; LINEAR [in]; ANGULAR [degrees]; X.XXX:; MANUFACTURING APPROVAL:

MUST BUY FEET, PREFERABLY LEVELING ONES

STANDARD DIMENSIONAL TOLERANCES:
PART LOCATION:

SOLIDWORKS Educational Product. For Instructional Use Only.

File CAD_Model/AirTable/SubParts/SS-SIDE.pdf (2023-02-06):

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

QTY: 2, TYPE: PLY

ROUND CORNERS ONCE CONNECTED TO TABLE

STANDARD DIMENSIONAL TOLERANCES:
PART LOCATION:

SOLIDWORKS Educational Product. For Instructional Use Only.

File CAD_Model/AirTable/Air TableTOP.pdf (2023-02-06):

TABLE TOP; LOCATOR; ROUND CORNERS AS DESIRED; 3"x3" PLY SQUARE x4; Honors Thesis; DESIGN ENGINEER: DESIGN APPROVAL:; PART NUMBER:; SHEET SCALE:; SHEET NUMBER:; Beech; As machined; LINEAR [in]; ANGULAR [degrees]; X.XXX:; MANUFACTURING APPROVAL:

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

PART NAME:
Air Table Top

STANDARD DIMENSIONAL TOLERANCES:
PART LOCATION:

SOLIDWORKS Educational Product. For Instructional Use Only.

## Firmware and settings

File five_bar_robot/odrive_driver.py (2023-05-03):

import time
import math
import numpy
import odrive
from odrive.enums import *
import sys

# setting path
sys.path.append("../parentdirectory")

import rclpy
from rclpy.node import Node
from sensor_msgs.msg import JointState, Joy
from std_msgs.msg import Float64MultiArray
from geometry_msgs.msg import PoseStamped, PointStamped
from Simulator.FiveBarDynamics import Dynamics


class OdriveDriver(Node):
    """Node Description"""

    def __init__(self):
        super().__init__("odrive_driver")

        self.subscription = self.create_subscription(
            msg_type=Joy, topic="joy", callback=self.joy_control, qos_profile=1
        )
        self.subscription2 = self.create_subscription(
            msg_type=PointStamped, topic="robot_pose", callback=self.robot_pose, qos_profile=1
        )
        self.subscription3 = self.create_subscription(
            msg_type=PointStamped, topic="puck_point", callback=self.puck_strike, qos_profile=1
        )
        self.joint_state_pub = self.create_publisher(msg_type=JointState, topic="joint_state", qos_profile=1)
        self.publisher = self.create_publisher(msg_type=Float64MultiArray, topic="encoder", qos_profile=1)
        self.robot_point = self.create_publisher(msg_type=PointStamped, topic="robot_point", qos_profile=1)
        # self.timer = self.create_timer(timer_period_sec = , callback = )

        self.get_logger().info("Finding all motors on drive")
        self.odrv0 = odrive.find_any()

        self.odrv0.axis0.motor.config.current_lim = 15
        self.odrv0.axis1.motor.config.current_lim = 15
        # self.odrv0.axis0.controller.config.vel_gain = 0.16
        # self.odrv0.axis0.controller.config.vel_integrator_gain = 0.32
        # self.odrv0.axis1.controller.config.vel_gain = 0.16
        # self.odrv0.axis1.controller.config.vel_integrator_gain = 0.32
        self.get_logger().warn("Completing startup calibration")
        # Commenting Out due to bugs
        # self.odrv0.axis0.requested_state = AXIS_STATE_ENCODER_INDEX_SEARCH
        # self.odrv0.axis1.requested_state = AXIS_STATE_ENCODER_INDEX_SEARCH

        # while self.odrv0.axis0.current_state != AXIS_STATE_IDLE or self.odrv0.axis1.current_state != AXIS_STATE_IDLE:
        #     time.sleep(0.1)
        self.odrv0.axis0.requested_state = AXIS_STATE_FULL_CALIBRATION_SEQUENCE
        self.odrv0.axis1.requested_state = AXIS_STATE_FULL_CALIBRATION_SEQUENCE
        while self.odrv0.axis0.current_state != AXIS_STATE_IDLE or self.odrv0.axis1.current_state != AXIS_STATE_IDLE:
            time.sleep(0.1)
        self.get_logger().info("Calibration complete")
        self.get_logger().warn("Setting Control as Closed Loop Control")

        self.odrv0.axis0.requested_state = AXIS_STATE_CLOSED_LOOP_CONTROL
        self.odrv0.axis1.requested_state = AXIS_STATE_CLOSED_LOOP_CONTROL

        self.dt = 1 / 20.0
        self.x = 0.25
        self.y = 0.6

        self.flag = False
        self.flag2 = True
        self.joy_flag = False

        self.print_log = False
        self.enc_log = False
        self.theta_log = False

        mass_matrix = [0.048, 0.048, 0.074 + 0.050, 0.074 + 0.050]
        length_matrix = [0.163, 0.163, 0.450, 0.450]
        a_length_matrix = [0.335, 0.335, 0.6025, 0.6025]
        bottom_length = 0.4925

        self.dynamics = Dynamics(bottom_length, mass_matrix, length_matrix, a_length_matrix, 0.35, 0.38, 0)

        self.declare_parameter("theta_offset1", 0.0)
        self.declare_parameter("theta_offset2", 0.0)

    def joy_control(self, msg=Joy):
        """Simple Joy Mapper from x-y translation to joy axes"""
        # Callback Params
        self.joy_flag = True if msg.buttons[7] == 1 else False

        if self.joy_flag is False:
            return

        self.offset1 = self.get_parameter("theta_offset1").get_parameter_value().double_value
        self.offset2 = self.get_parameter("theta_offset2").get_parameter_value().double_value

        # Flags for soft E-Stops and Neutral
        self.flag = True if msg.buttons[8] == 1 else False
        self.flag2 = True if msg.buttons[4] == 0 else False

        self.print_log = True if msg.buttons[0] == 1 else False
        self.enc_log = True if msg.buttons[1] == 1 else False
        self.theta_log = True if msg.buttons[3] == 1 else False

        if self.flag is True:
            self.odrv0.axis0.requested_state = AXIS_STATE_IDLE
            self.odrv0.axis1.requested_state = AXIS_STATE_IDLE
            self.get_logger().warn("ODrive in Idle State")
            return
        else:
            self.odrv0.axis0.requested_state = AXIS_STATE_CLOSED_LOOP_CONTROL
            self.odrv0.axis1.requested_state = AXIS_STATE_CLOSED_LOOP_CONTROL

        y_vel = round((msg.axes[1] / 8), 3)
        x_vel = round(((msg.axes[0] / 8) * -1.0), 2)

        self.x += round(x_vel * self.dt, 3)
        self.y += round(y_vel * self.dt, 3)

        self.x = min(self.x, 0.7)
        self.x = max(self.x, -0.2)
        self.y = min(self.y, 0.85)
        self.y = max(self.y, 0.25)

        self.x, self.y = self.dynamics.get_closest_solution(self.x, self.y, 0.01)
        theta1, theta2, theta3, theta4 = self.dynamics.inverse_kinematics(self.x, self.y)[0]

        if self.print_log is True:
            self.get_logger().info(f"x = {self.x}, y = {self.y}")

        if self.flag2 is True:
            theta1 = math.pi / 2
            theta2 = math.pi / 2
            self.get_logger().info("Setting To 90 Degrees")

        theta1 = -(theta1 + math.radians(self.offset1)) / (
            2 * math.pi
        )  # converting to rotations where 2pi is one rotation.
        theta2 = -(theta2 + math.radians(self.offset2)) / (2 * math.pi)

        if self.theta_log is True:
            self.get_logger().info(f"theta1 = {math.degrees(-theta1)}, theta2 = {math.degrees(-theta2)}")

        self.odrv0.axis0.controller.input_pos = theta1
        self.odrv0.axis1.controller.input_pos = theta2

        encoder1 = self.odrv0.axis0.encoder.pos_estimate
        encoder2 = self.odrv0.axis1.encoder.pos_estimate

        if self.enc_log is True:
            self.get_logger().info(f"Encoder1 = {encoder1}, Encoder2 = {encoder2}")

        msg_encoder = Float64MultiArray()
        msg_encoder.data = [encoder1, encoder2]
        self.publisher.publish(msg_encoder)
        msg_joint_state = JointState()
        msg_joint_state.position = [theta1, theta2, theta3, theta4]
        msg_joint_state.position = [self.x, self.y, theta1, theta2, theta3, theta4]
        msg_joint_state.name = ["EndPointPoseX", "EndPointPoseY", "Joint1", "Joint2", "Joint3", "Joint4"]
        self.joint_state_pub.publish(msg_joint_state)

    def robot_pose(self, msg=PointStamped):

        if self.joy_flag is True:
            return

        self.offset1 = self.get_parameter("theta_offset1").get_parameter_value().double_value
        self.offset2 = self.get_parameter("theta_offset2").get_parameter_value().double_value

        self.x = msg.point.x
        self.y = msg.point.y
        self.x = min(self.x, 0.7)
        self.x = max(self.x, -0.2)
        self.y = min(self.y, 0.85)
        self.y = max(self.y, 0.1)

        self.x, self.y = self.dynamics.get_closest_solution(self.x, self.y, 0.01)
        theta1, theta2, theta3, theta4 = self.dynamics.inverse_kinematics(self.x, self.y)[2]

        theta1 = -(theta1 + math.radians(self.offset1)) / (
            2 * math.pi
        )  # converting to rotations where 2pi is one rotation.
        theta2 = -(theta2 + math.radians(self.offset2)) / (2 * math.pi)

        self.odrv0.axis0.controller.input_pos = theta1
        self.odrv0.axis1.controller.input_pos = theta2

        encoder1 = self.odrv0.axis1.encoder.pos_estimate
        encoder2 = self.odrv0.axis1.encoder.pos_estimate

        msg_encoder = Float64MultiArray()
        msg_encoder.data = [encoder1, encoder2]
        self.publisher.publish(msg_encoder)
        msg_joint_state = JointState()
        msg_joint_state.position = [self.x, self.y, theta1, theta2, theta3, theta4]
        msg_joint_state.name = ["EndPointPoseX", "EndPointPoseY", "Joint1", "Joint2", "Joint3", "Joint4"]
        self.joint_state_pub.publish(msg_joint_state)

    def puck_strike(self, msg=PointStamped):
        if self.joy_flag is True:
            return

        self.offset1 = self.get_parameter("theta_offset1").get_parameter_value().double_value
        self.offset2 = self.get_parameter("theta_offset2").get_parameter_value().double_value

        self.x = msg.point.x
        self.y = msg.point.y
        self.x = min(self.x, 0.7)
        self.x = max(self.x, -0.2)
        self.y = min(self.y, 0.85)
        self.y = max(self.y, 0.15)

        # self.y = 0.5

        self.x, self.y = self.dynamics.get_closest_solution(self.x, self.y, 0.01)
        theta1, theta2, theta3, theta4 = self.dynamics.inverse_kinematics(self.x, self.y)[2]

        theta1 = -(theta1 + math.radians(self.offset1)) / (
            2 * math.pi
        )  # converting to rotations where 2pi is one rotation.
        theta2 = -(theta2 + math.radians(self.offset2)) / (2 * math.pi)

        self.odrv0.axis0.controller.input_pos = theta1
        self.odrv0.axis1.controller.input_pos = theta2

        encoder1 = self.odrv0.axis1.encoder.pos_estimate
        encoder2 = self.odrv0.axis1.encoder.pos_estimate

        msg_encoder = Float64MultiArray()
        msg_encoder.data = [encoder1, encoder2]
        self.publisher.publish(msg_encoder)
        msg_joint_state = JointState()
        msg_joint_state.position = [self.x, self.y, theta1, theta2, theta3, theta4]
        msg_joint_state.name = ["EndPointPoseX", "EndPointPoseY", "Joint1", "Joint2", "Joint3", "Joint4"]
        self.joint_state_pub.publish(msg_joint_state)
        msg_robot_point = PointStamped()
        msg_robot_point.point.x = self.x
        msg_robot_point.point.y = self.y
        msg_robot_point.header.frame_id = "robot"
        msg_robot_point.header.stamp = self.get_clock().now().to_msg()
        self.robot_point.publish(msg_robot_point)


def main(args=None):
    rclpy.init(args=args)

    odrive_driver = OdriveDriver()
    try:
        rclpy.spin(odrive_driver)
    except KeyboardInterrupt:
        odrive_driver.get_logger().warn("Setting Motor States to Idle, Shutting Down Node")
        odrive_driver.odrv0.axis0.requested_state = AXIS_STATE_IDLE
        odrive_driver.odrv0.axis1.requested_state = AXIS_STATE_IDLE
    finally:
        odrive_driver.destroy_node()
        rclpy.shutdown()


if __name__ == "__main__":
    main()

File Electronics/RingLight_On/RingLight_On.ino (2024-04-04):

#include <Adafruit_NeoPixel.h>

// Which pin on the Arduino is connected to the NeoPixels?
// On a Trinket or Gemma we suggest changing this to 1:
#define LED_PIN    6

// How many NeoPixels are attached to the Arduino?
#define LED_COUNT 24

// Declare our NeoPixel strip object:
Adafruit_NeoPixel strip(LED_COUNT, LED_PIN, NEO_GRB + NEO_KHZ800);
// Argument 1 = Number of pixels in NeoPixel strip
// Argument 2 = Arduino pin number (most are valid)
// Argument 3 = Pixel type flags, add together as needed:
//   NEO_KHZ800  800 KHz bitstream (most NeoPixel products w/WS2812 LEDs)
//   NEO_KHZ400  400 KHz (classic 'v1' (not v2) FLORA pixels, WS2811 drivers)
//   NEO_GRB     Pixels are wired for GRB bitstream (most NeoPixel products)
//   NEO_RGB     Pixels are wired for RGB bitstream (v1 FLORA pixels, not v2)
//   NEO_RGBW    Pixels are wired for RGBW bitstream (NeoPixel RGBW products)

void setup() {
  strip.begin();
  strip.show(); // Initialize all pixels to 'off'
  uint8_t intensity = 255;
  uint32_t white = strip.Color(intensity, intensity, intensity);
  strip.fill(white);
  strip.show();
}

void loop() {
  // put your main code here, to run repeatedly:
  // Add checking to validate if the color should be changed or something else.
}

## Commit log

2022-10-18 Starting to find motors, simulation mostly working (optimization to come)
    [RI100-210120.SLDPRT, RI100-210120.stp]
2023-01-07 Added a bunch of CAD files! Just have to design the press fits.
    [0.500 ID x 0.875 OD x 0.281 WD (Radial Bearing) (217-3337).SLDPRT, 0.500 ID x 0.875 OD x 0.281 WD (Radial Bearing) (217-3337).step, 91290A100_Black-Oxide Alloy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]
2023-01-13 Continuing to develop the CAD
    [2.54 mm DUPONT MALE PIN HEADER, IO, 2X20, RPi4ModelB.SLDPRT, 2.54 mm DUPONT MALE PIN HEADER, IO, 2X40, RPi4ModelB.SLDPRT, 2.54 mm DUPONT MALE PIN HEADER, POE, 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]
2023-01-26 Updated CAD
    [6455K8_Plastic Ball Bearing.SLDPRT, 91290A140_Alloy Steel Socket Head Screw.SLDPRT, Air Table.SLDPRT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]
2023-02-06 Added Drawings for AirTable, also modified several parts
    [60355K45_Ball Bearing.SLDPRT, 6455K8_Plastic Ball Bearing.SLDPRT, 91290A140_Alloy Steel Socket Head Screw.SLDPRT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]
2023-02-09 Added cooling, mounting, and nearly finished everything CAD
    [60355K45_Ball Bearing.SLDPRT, 91290A180_Alloy Steel Socket Head Screw.SLDPRT, 94900A011_Nylon Hex Nut.SLDPRT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]
2023-02-09 Finished some more all CAD bits. Need to only make one more change now though, which is find a position for the limit switches.
    [Edge_Guard.SLDPRT, Edge_Guard.STL, Elbow1V2.SLDPRT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]
2023-04-05 CAD finished, CAM processing
    [1_Robot_Elbow1V2.STL, 1_Robot_Elbow2V2.STL, 2_Robot_EndJoint_Spacer.STL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]
2023-04-11 Fixed the primary bugs and added function descriptions to the 5-bar robot class. Need to finish two more functions in it before I can start testing on the actual robot though. Additionally, more code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
    [2x_StatorWorkHolding.STL, StatorWorkHolding.SLDPRT, StatorWorkHolding.STEP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]
2023-04-13 Updated the dynamics class again and fixed a few bugs!
    [1_Robot_Elbow1V2.STL, 1_Robot_Elbow2V2.STL, 2_Robot_EndJoint_Spacer.STL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]
2023-04-16 Added Puck tracking. Testing Odrive
2023-04-17 Found a bug in my animation, do not think it is displaying real time. Updated some other small things and added a requirements.txt file. Finally updated the Odrive firmware with stlink.
2023-04-20 Added basic path following
    [Elbow1V2.SLDPRT, Elbow2V2.SLDPRT, LinkageMainV2.SLDPRT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]
2023-04-26 Fixed get closest point
    [Linkage_ASM.SLDASM]
2024-04-04 Upating with resent changes
    [NeopixelRinglightMount.SLDPRT, NeopixelRinglightMount.STL, Save_LinkageMainV2.SLDPRT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]
